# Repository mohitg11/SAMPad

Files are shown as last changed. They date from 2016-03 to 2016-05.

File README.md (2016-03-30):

# SAMPad

This is a custom numeric pad that is designed to be usable on the right side of the keyboard or on the left (With a mirrored layout if required).
There is a gap in the top row and the second row of 1.25U. The top row can be broken off by simply scoring the two brifges and snapping.
The bottom 5 rows can then be used in conjunction with a 60%/65% keyboard.

SAMPad stands for Sundstrand Adding Machine. David Sundstrand was the inventor of the 10-key adding machine, the layout of which is used till date on most numeric pads. This is a humble dedication to the great man.

#Features
- Open Source Design
- Fully Programmable Keys
- Numpad can be mirrored for use on the left side of the main keyboard.
- Multiple layers
- Alps/Cherry (PCB/Plate) support
- PCB mount stabs supported
- Backlight, LED on bottom for windowed keycaps
- 6 Indicator LEDs, 4 on the top row and one on either Num Lock positions (Regular and mirrored)
- 4 SMD RGB LEDs on the bottom of the PCB for under/side glow
- SMD (SOD-123) diodes only
- Individual resistors for the LEDs not required as it uses a dedicated LED driver
- Using large (0805) capacitors and resistors so it is easier to hand-solder
- Possibility to add a buzzer
- Possibility to add a rotary dial on the top-right most key position for changing volume, LED brightness, etc.

#Layout options decided/implemented:
- Standard numpad with extra row on top with a 1.25U vertical offset that matches most TKL boards.
- Possibility for upto 5*4 + 4 keys layout
- Mirrored numpad layout for use on left side of main keyboard

In the below image you can see the different options available.
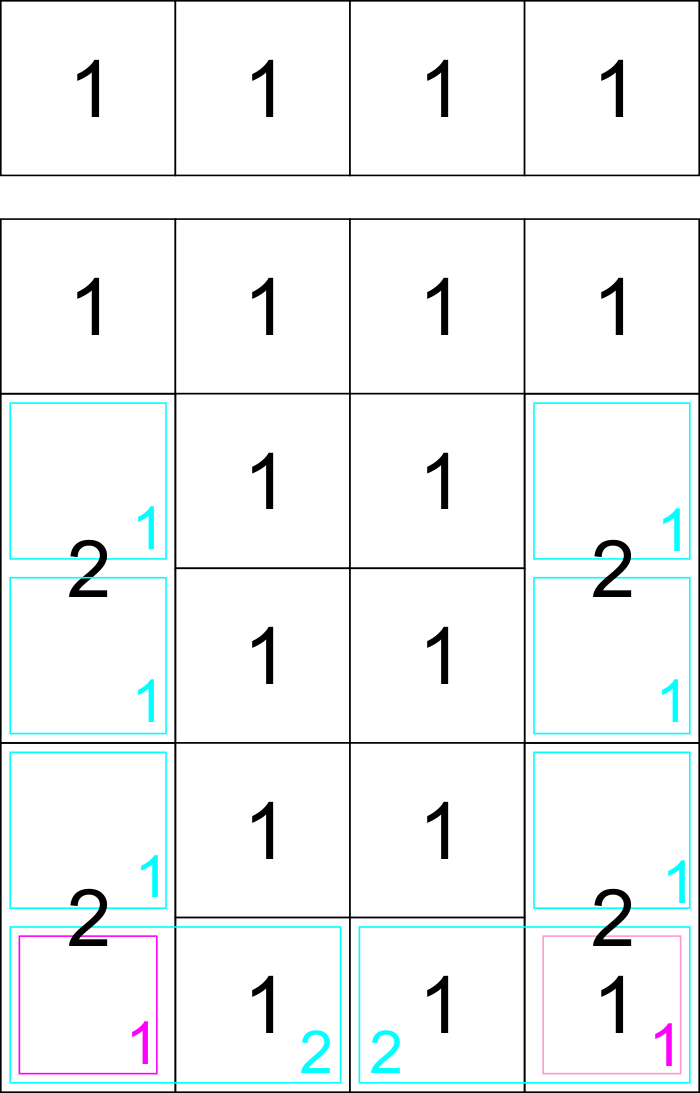
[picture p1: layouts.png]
Layout Options


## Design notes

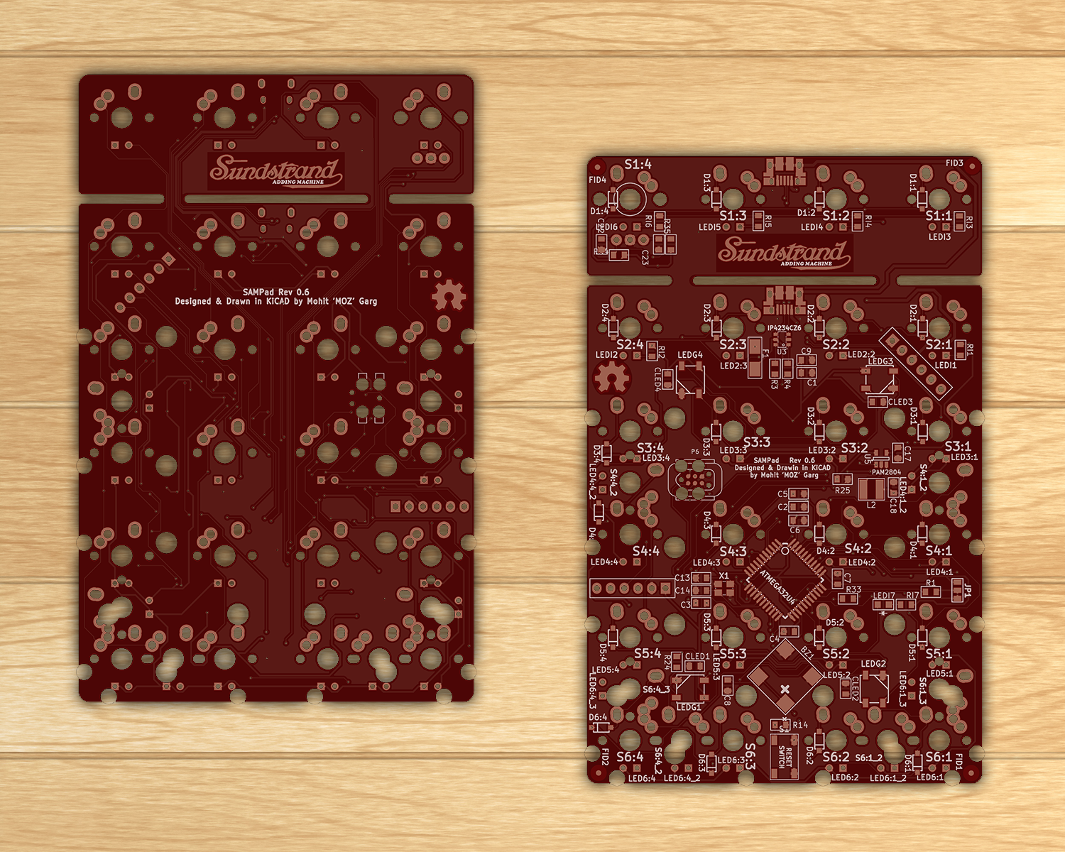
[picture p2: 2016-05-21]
PCB.png

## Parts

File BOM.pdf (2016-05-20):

# | Ref | Value | Qty | Description | Product | Vendor

1 | C1, C2 | 1uF | 2 | CAP CER 1UF 10V 10% X7R 0805 | CC0805KKX7R6BB105 | Yageo
2 | C13, C14 | 8pF | 2 | CAP CER 8PF 50V NP0 0805 | CC0805DRNPO9BN8R0 | Yageo
3 | C9, C17, C18 | 10uF | 3 | CAP CER 10UF 6.3V X5R 0805 | CC0805KKX5R5BB106 | Yageo
4 | CLED1 ‐ CLED4, C3‐C7 | 0.1 uF | 9 | CAP CER 0.1UF 16V X7R 0805 | CL21B104KOANNNC | Yageo
5 | D1:1 | 1N4148 | 24 | 1N4148 SOD123 DIODE | 1N4148W‐FDICT‐ND | Diodes Inc
6 | F1 | PTC FUSE | 1 | PTC RESTTBLE 1.0A 6V CHIP 1206 | 0ZCJ0100FF2E | Bel Fuse Inc
7 | L2 | 4.7uH | 1 | FIXED IND 4.7UH 1.9A 84 MOHM SMD | SRN4018‐4R7M | Bourns Inc
8 | LED1:1 ‐ LED6:4, :LEDI1 ‐ LEDI6 | LED | 24 | 2x3x4mm 1.8mm 3mm flangeless LED
9 | LEDG1 ‐ LEDG4 | WS2812B | 4 | LED RGB WS2812B W/DVR 4SMD 10PK | WS2812B | WorldSemi
10 | LEDI7 | LED | 1 | 0805 SMD LED
11 | P1 | USB_CONN | 1 | USB Micro B Female | 10103594‐0001LF | Amphenol
12 | R1 | 10k | 1 | RES SMD 10K OHM 1% 1/8W 0805 | RC0805FR‐0710KL | Yageo
13 | R24 | 330 | 1 | RES SMD 330 OHM 1% 1/8W 0805 | RC0805FR‐07330RL | Yageo
14 | R25 | RLED | 1 | Resistor to set LED current select 0.1/I | RL0805FR‐7W0R5L | Yageo
15 | R3, R4 | 22 | 2 | RES SMD 22 OHM 5% 1/8W 0805 | RC0805FR‐0722RL | Yageo
16 | R14 | 100k | 1 | RES SMD 100K OHM 1% 1/8W 0805 | RC0805FR‐07100KL | Yageo
17 | RI1 ‐ RI7 | 470 | 7 | 0805 Resistor for LED | RC0805FR‐07470KL | Yageo
18 | S1 | TAC_SWITCH | 1 | SWITCH TACTILE SPST‐NO 0.02A 15V | PTS525SM15SMTR2 LFS | C&K Components
19 | S1:1 | SW | 24 | MX Alps or compatible switch
20 | U1 | ATMEGA32U4 | 1 | IC MCU 8BIT 32KB FLASH 44TQFP | ATMEGA32U4‐AU | Atmel
21 | U3 | IP4234CZ6 | 1 | TVS DIODE 5.5VWM 6TSOP | IP4234CZ6 | NXP
22 | U5 | PAM2804 | 1 | LED Driver IC 1 Output DC DC Buck 1A | PAM2804AAB010 | Diodes Inc
23 | X1 | 16Mhz | 1 | Crystal 16.0000MHz 15ppm 8pF 50 Ohm | NX3225SA‐16.000MHZ‐STD‐CSR‐1 | NDK
# | Buzzer (Optional)

1 | BZ1 | BUZZER | 1 | BUZZER MAGNETIC 3.6V 8.5MM SMD | SMT‐0931‐S‐R | PUI Audio Inc
2 | C8 | 0.1 uF | 1 | CAP CER 0.1UF 16V X7R 0805 | CL21B104KOANNNC | Yageo
3 | R33 | 100 | 1 | RES SMD 100 OHM 1% 1/8W 0805 | RC0805FR‐07100RL | Yageo
# | Encoder (Optional)

1 | C22, C23 | 1uF | 2 | CAP CER 1UF 10V 10% X7R 0805 | CC0805KKX7R6BB105 | Yageo
2 | R34, R35 | 10k | 2 | RES SMD 10K OHM 1% 1/8W 0805 | RC0805FR‐0710KL | Yageo
3 | S2 | ENCODER | 1 | ENCODER ROTARY | PEC12R‐4017F‐N0024 | Bourns Inc

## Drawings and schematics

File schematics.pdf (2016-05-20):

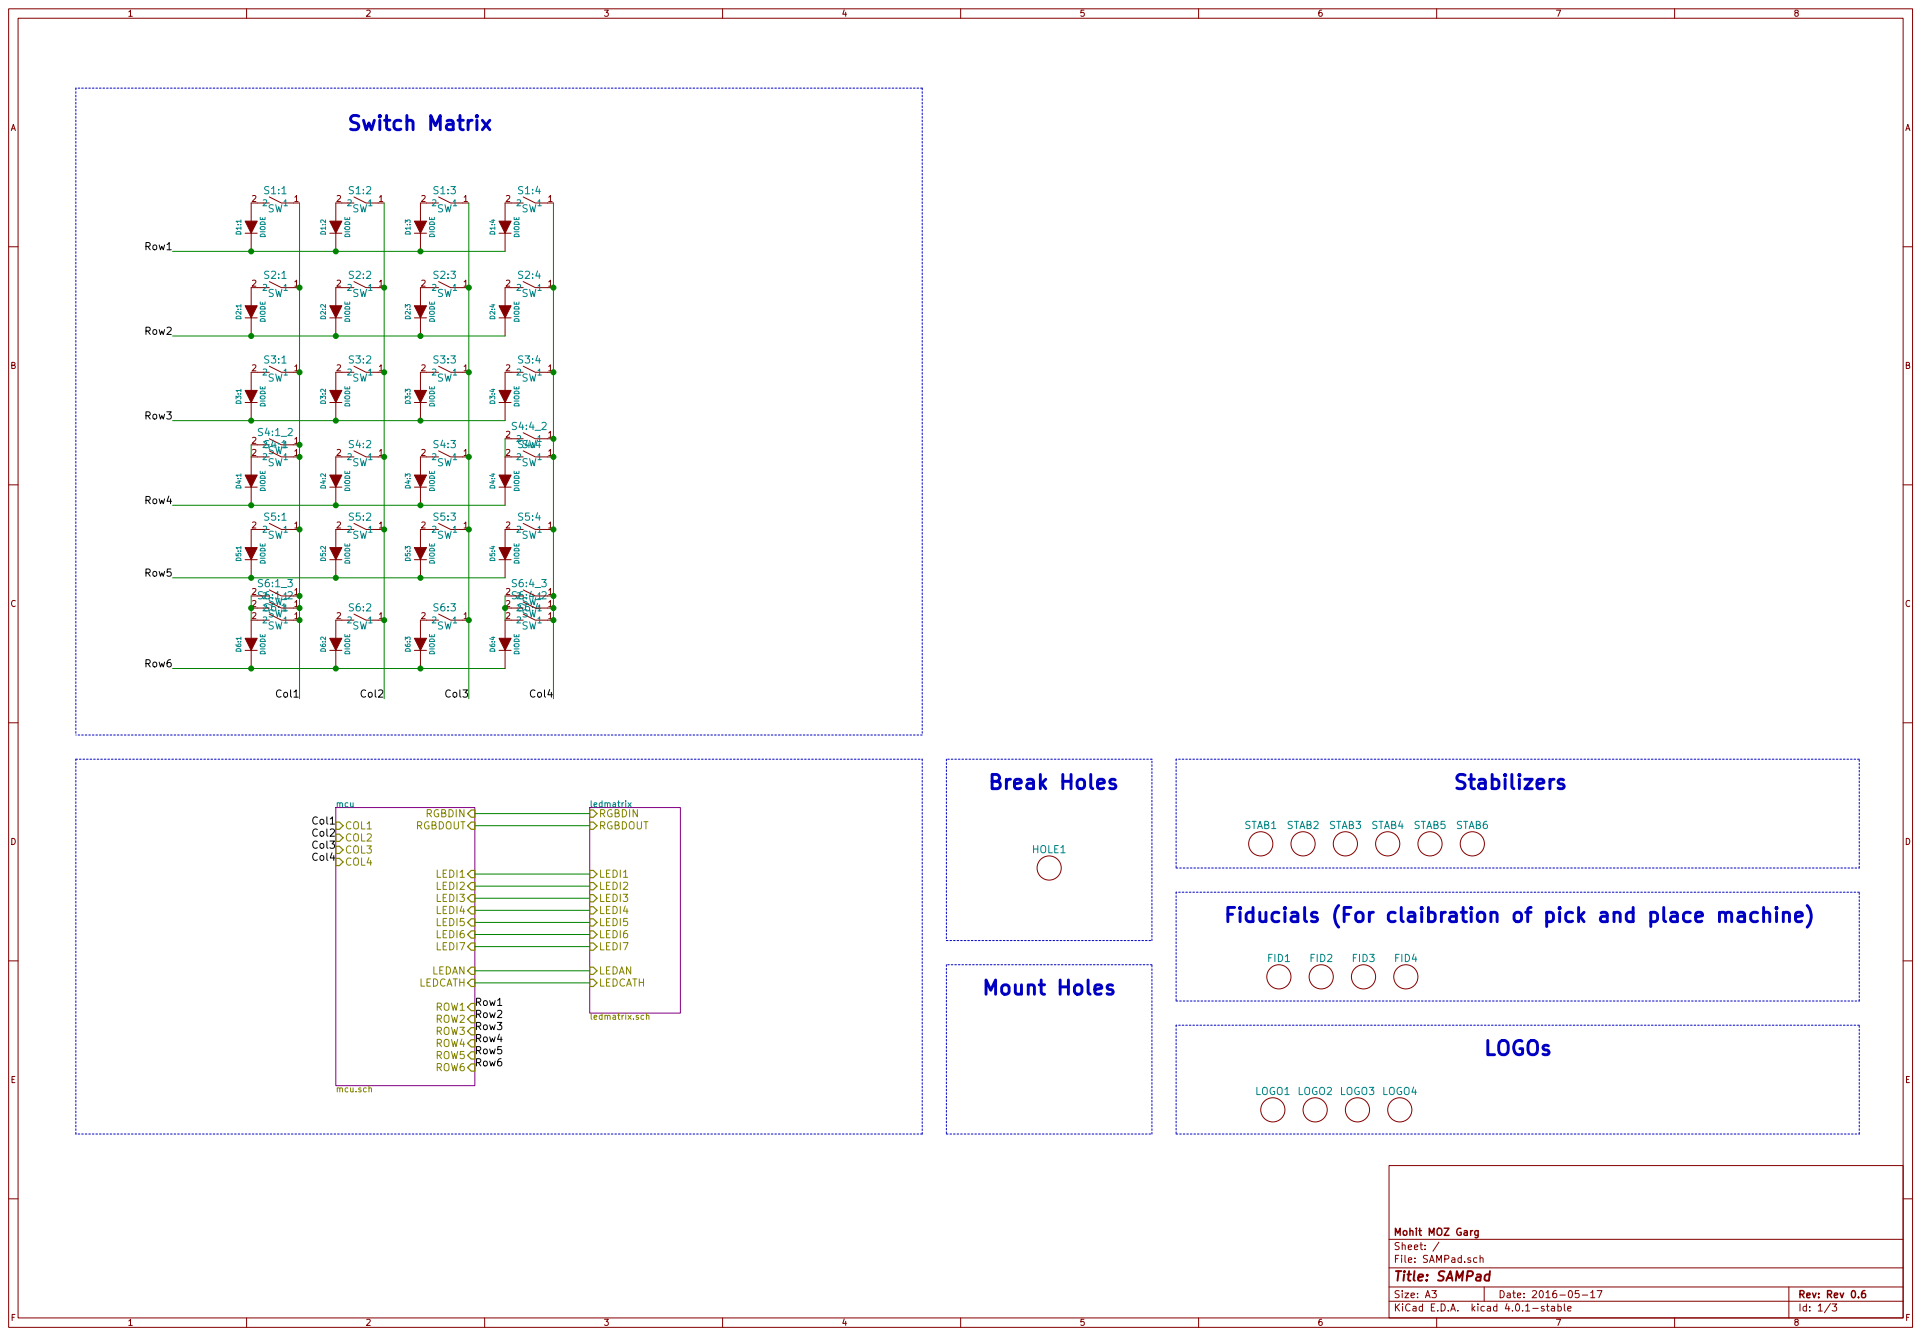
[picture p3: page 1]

Fiducials (For claibration of pick and place machine)

File: SAMPad.sch Sheet: / Mohit MOZ Garg

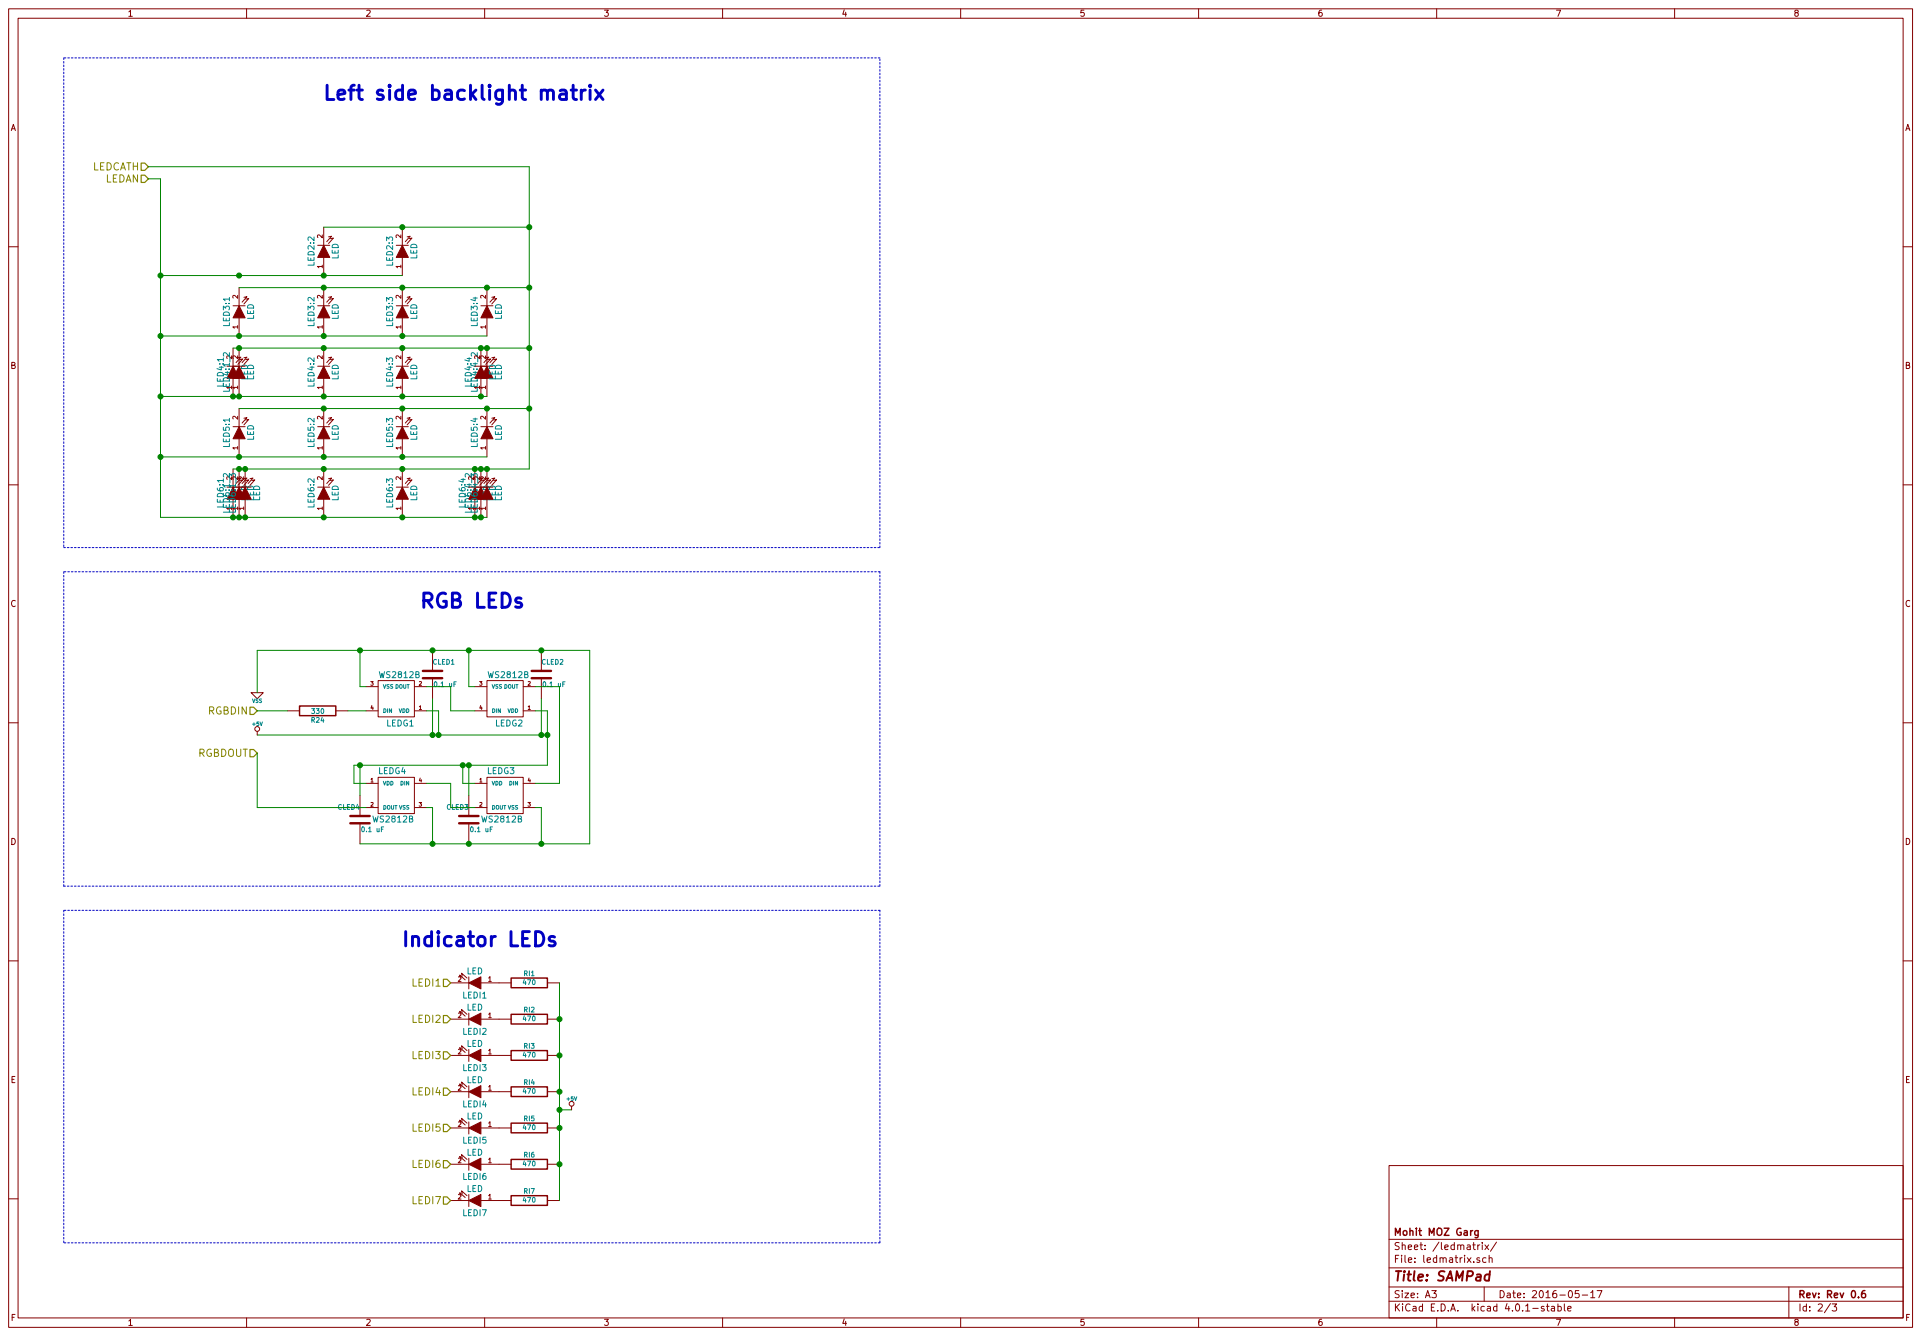
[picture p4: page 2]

Left side backlight matrix

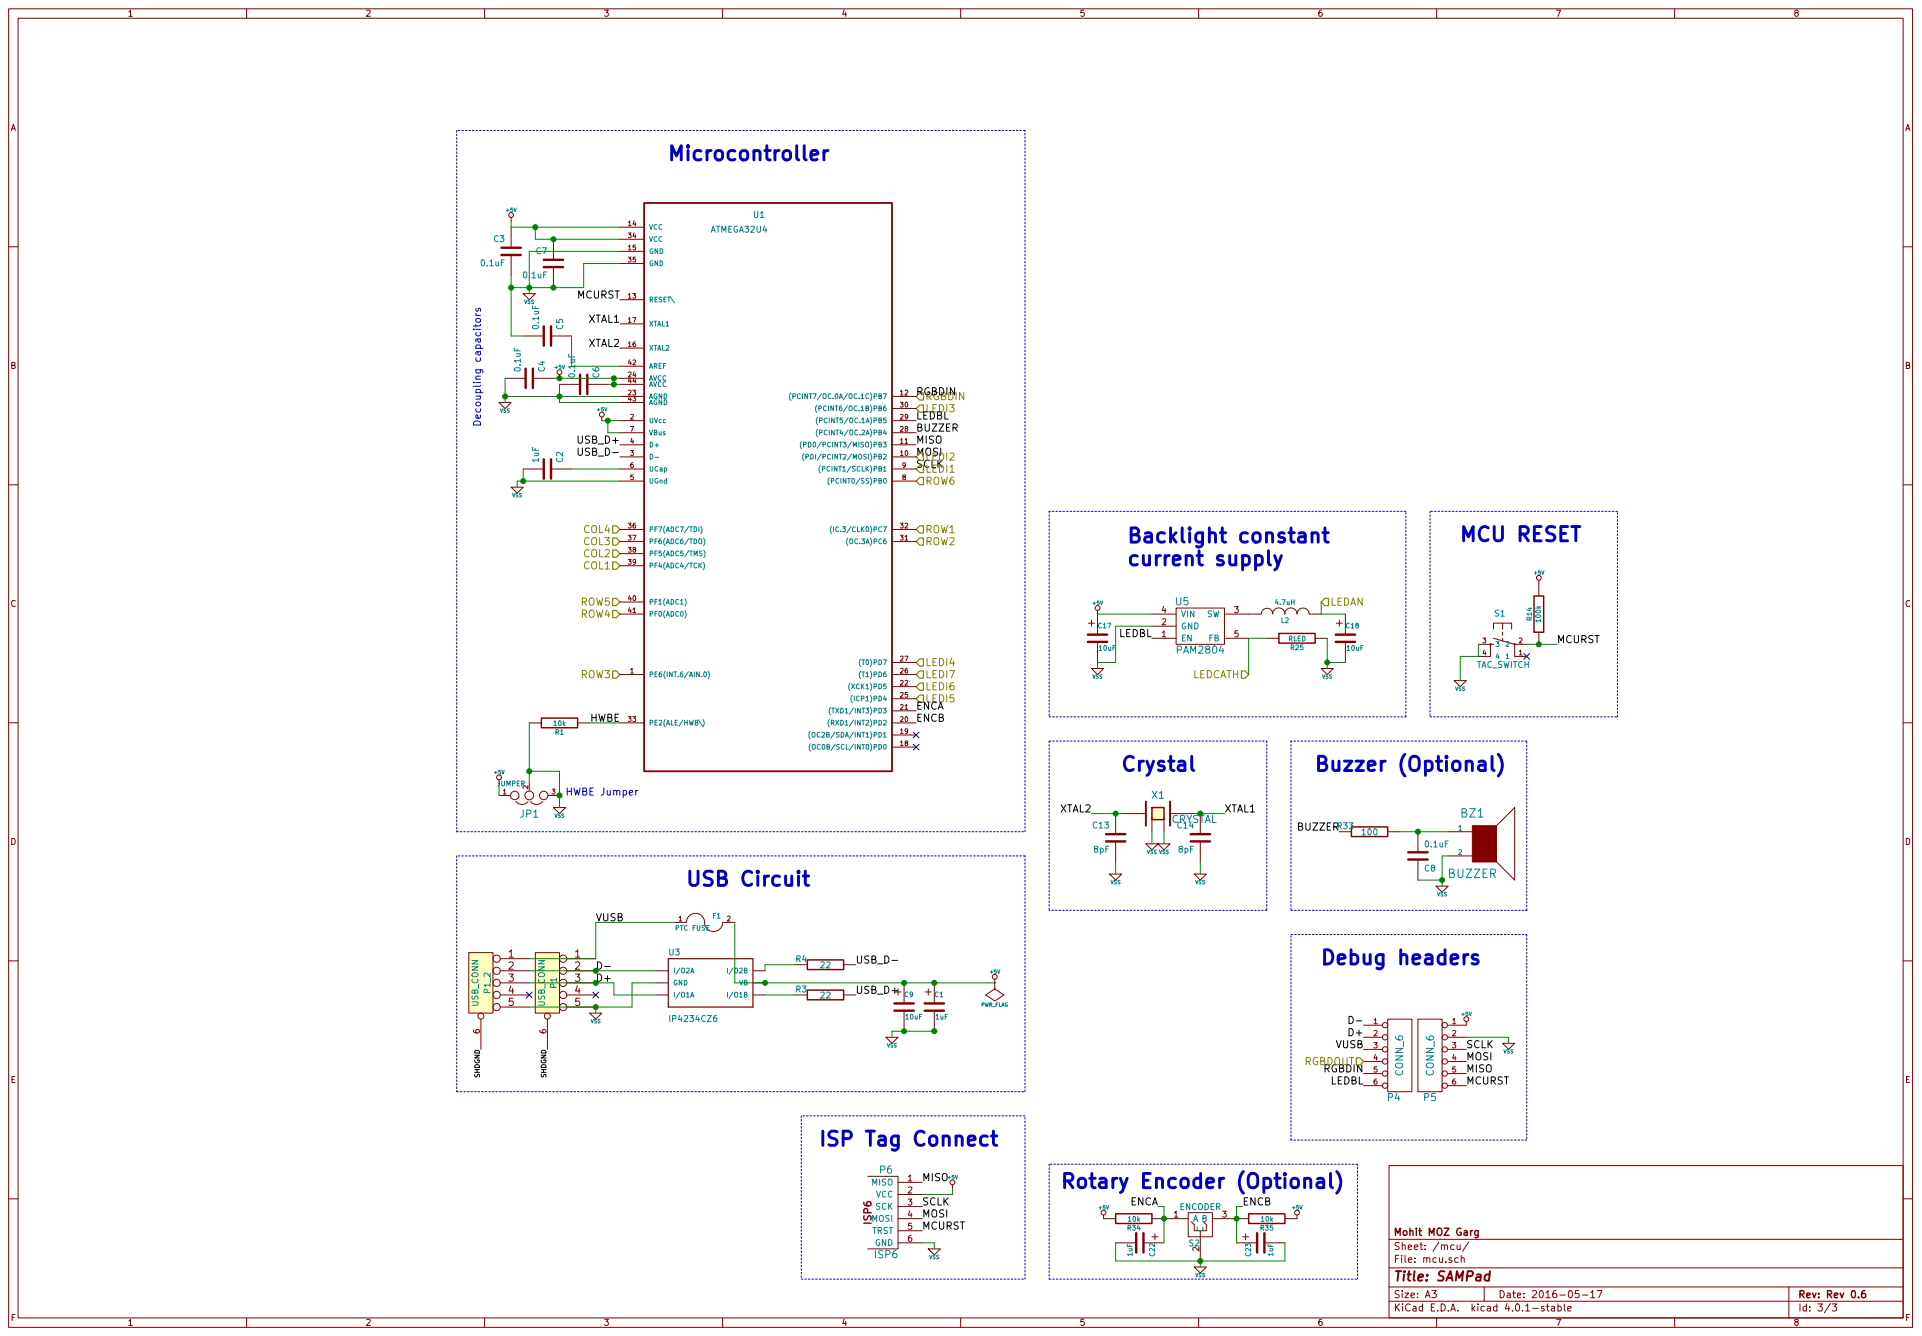
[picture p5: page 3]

VSS BUZZER Buzzer (Optional)

File: mcu.sch Sheet: /mcu/ Mohit MOZ Garg

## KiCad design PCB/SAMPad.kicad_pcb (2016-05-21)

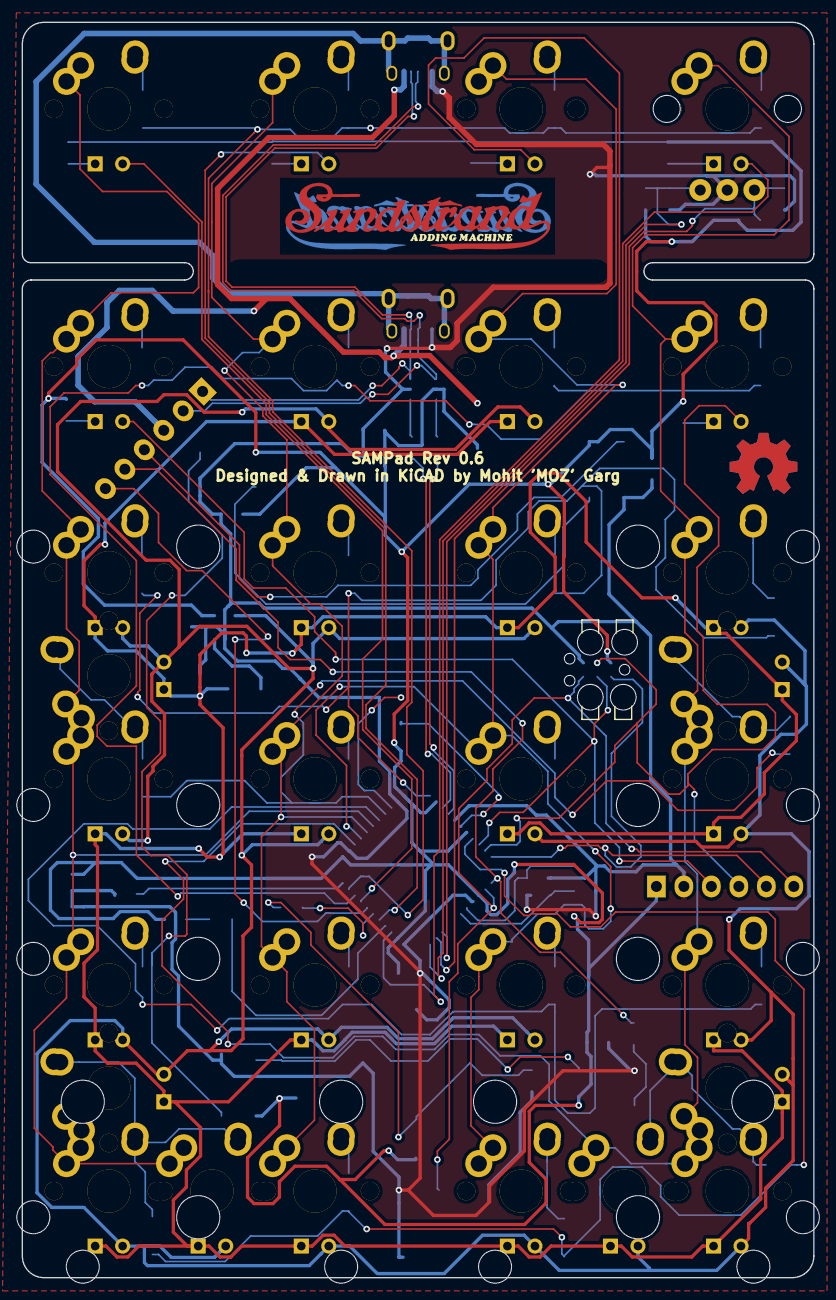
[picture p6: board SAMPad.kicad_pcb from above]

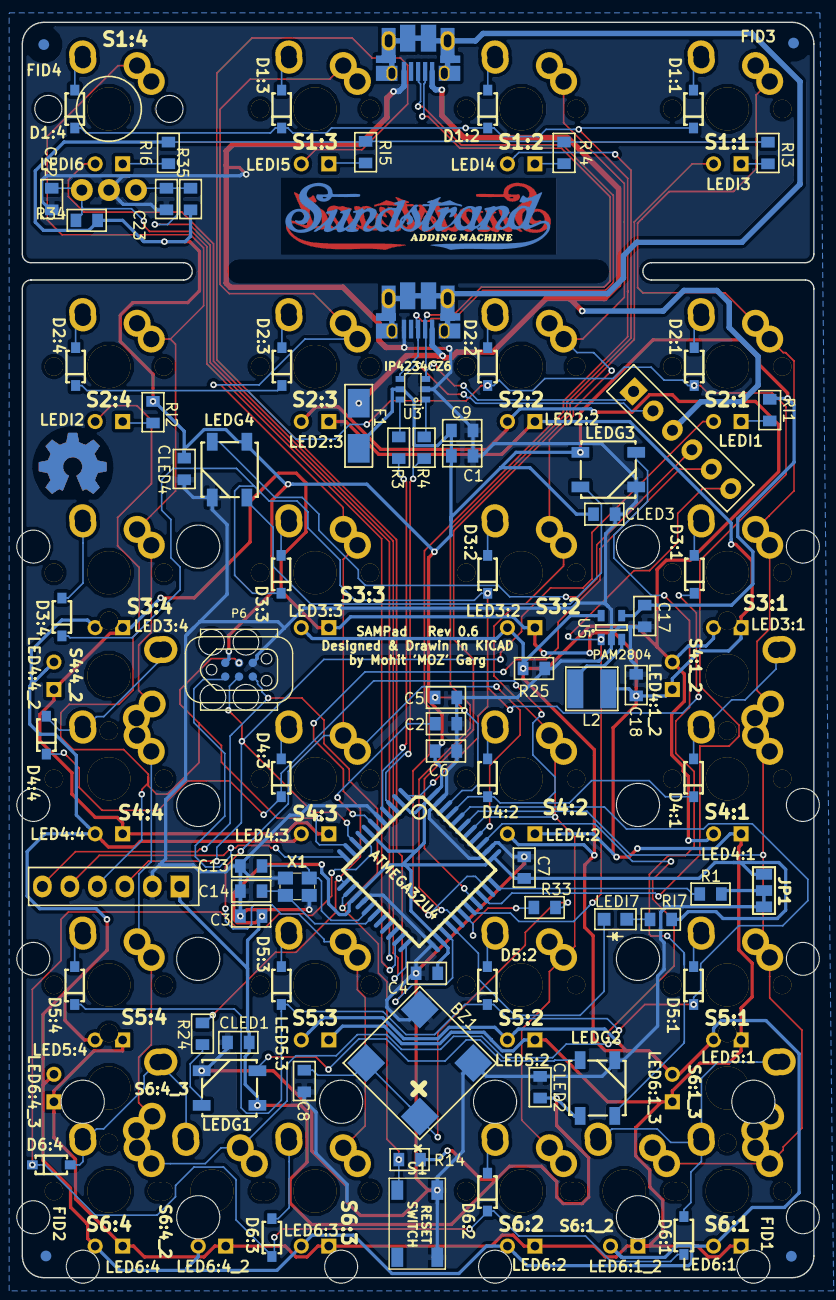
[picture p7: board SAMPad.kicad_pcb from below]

Board: 2 copper layers, 73.2 x 116.0 mm, 154 parts (85 on the bottom side), 79 nets.

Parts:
BZ1: BUZZER; BUZZER_SMT
C1, C2, C22, C23: 1uF; SMD_0805
C3, C4, C5, C6, C7, C8: 0.1uF; SMD_0805
C9, C17, C18: 10uF; SMD_0805
C13, C14: 8pF; SMD_0805
CLED1, CLED2, CLED3, CLED4: 0.1 uF; SMD_0805
D1:1, D1:2, D1:3, D1:4, D2:1, D2:2, D2:3, D2:4, D3:1, D3:2, D3:3, D3:4, D4:1, D4:2, D4:3, D4:4, D5:1, D5:2, D5:3, D5:4, D6:1, D6:2, D6:3, D6:4: DIODE; SOD123-DIODE
F1: PTC FUSE; Fuse_SMD1206
FID1, FID2, FID3, FID4: MISC; FID
HOLE1: MISC; FID
JP1: JUMPER; JUMPER_SMD_3
L2: 4.7uH; Inductor_Bourn_4mmx4mm
LED2:2, LED2:3, LED3:1, LED3:2, LED3:3, LED3:4, LED4:1, LED4:1_2, LED4:2, LED4:3, LED4:4, LED4:4_2, LED5:1, LED5:2, LED5:3, LED5:4, LED6:1, LED6:1_2, LED6:1_3, LED6:2, LED6:3, LED6:4, LED6:4_2, LED6:4_3: LED; INSW_LEDS_REG
LEDG1, LEDG2, LEDG3, LEDG4: WS2812B
LEDI1, LEDI2, LEDI3, LEDI4, LEDI5, LEDI6: LED; INSW_LEDS_REG
LEDI7: LED; LED_0805
LOGO1, LOGO2: MISC; SAMPad-Logo
LOGO3, LOGO4: MISC; OSHW
P1, P1_2: USB_CONN; USB_Micro-B
P4, P5: CONN_6; Pin_Header_1x06
P6: ISP6; TC2030_BIG
R1, R34, R35: 10k; SMD_0805
R3, R4: 22; SMD_0805
R14: 100k; SMD_0805
R24: 330; SMD_0805
R25: RLED; SMD_0805
R33: 100; SMD_0805
RI1, RI2, RI3, RI4, RI5, RI6, RI7: 470; SMD_0805
S1: TAC_SWITCH; TACT_5.2x5.2
S1:1, S1:2, S1:3, S1:4, S2:1, S2:2, S2:3, S2:4, S3:1, S3:2, S3:3, S3:4, S4:1, S4:1_2, S4:2, S4:3, S4:4, S4:4_2, S5:1, S5:2, S5:3, S5:4, S6:1, S6:1_2, S6:1_3, S6:2, S6:3, S6:4, S6:4_2, S6:4_3: SW; MXALPS2
S2: ENCODER; ENCODER_12MM
STAB1, STAB2, STAB3, STAB4, STAB5, STAB6: MISC; MX_200
U1: ATMEGA32U4; TQFP44
U3: IP4234CZ6; SOT457
U5: PAM2804; SOT-23-5
X1: CRYSTAL; NX3225SA

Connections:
+5V: C1.1, C3.1, C4.1, C6.1, C7.1, C9.1, C17.1, CLED1.2, CLED2.2, CLED3.1, CLED4.1, F1.2, JP1.1, LEDG1.1, LEDG2.1, LEDG3.1, LEDG4.1, P5.1, P6.2, R14.2, R34.2, R35.1, RI1.2, RI2.2, RI3.2, RI4.2, RI5.2, RI6.2, RI7.2, U1.2, U1.7, U1.14, U1.24, U1.34, U1.44, U3.5, U5.4
/ledmatrix/LEDAN: C18.1, L2.2, LED2:2.1, LED2:3.1, LED3:1.1, LED3:2.1, LED3:3.1, LED3:4.1, LED4:1.1, LED4:1_2.1, LED4:2.1, LED4:3.1, LED4:4.1, LED4:4_2.1, LED5:1.1, LED5:2.1, LED5:3.1, LED5:4.1, LED6:1.1, LED6:1_2.1, LED6:1_3.1, LED6:2.1, LED6:3.1, LED6:4.1, LED6:4_2.1, LED6:4_3.1
/ledmatrix/LEDCATH: LED2:2.2, LED2:3.2, LED3:1.2, LED3:2.2, LED3:3.2, LED3:4.2, LED4:1.2, LED4:1_2.2, LED4:2.2, LED4:3.2, LED4:4.2, LED4:4_2.2, LED5:1.2, LED5:2.2, LED5:3.2, LED5:4.2, LED6:1.2, LED6:1_2.2, LED6:1_3.2, LED6:2.2, LED6:3.2, LED6:4.2, LED6:4_2.2, LED6:4_3.2, R25.2, U5.5
/ledmatrix/LEDI1: LEDI1.2, P5.3, P6.3, U1.9
/ledmatrix/LEDI2: LEDI2.2, P5.4, P6.4, U1.10
/ledmatrix/LEDI3: LEDI3.2, U1.30
/ledmatrix/LEDI4: LEDI4.2, U1.27
/ledmatrix/LEDI5: LEDI5.2, U1.25
/ledmatrix/LEDI6: LEDI6.2, U1.22
/ledmatrix/LEDI7: LEDI7.2, U1.26
/ledmatrix/RGBDIN: P4.5, R24.2, U1.12
/ledmatrix/RGBDOUT: LEDG4.2, P4.4
/mcu/BUZZER: R33.1, U1.28
/mcu/COL1: S1:1.1, S2:1.1, S3:1.1, S4:1.1, S4:1_2.1, S5:1.1, S6:1.1, S6:1_2.1, S6:1_3.1, U1.39
/mcu/COL2: S1:2.1, S2:2.1, S3:2.1, S4:2.1, S5:2.1, S6:2.1, U1.38
/mcu/COL3: S1:3.1, S2:3.1, S3:3.1, S4:3.1, S5:3.1, S6:3.1, U1.37
/mcu/COL4: S1:4.1, S2:4.1, S3:4.1, S4:4.1, S4:4_2.1, S5:4.1, S6:4.1, S6:4_2.1, S6:4_3.1, U1.36
/mcu/D+: P1.3, P1_2.3, P4.2, U3.4
/mcu/D-: P1.2, P1_2.2, P4.1, U3.3
/mcu/ENCA: C22.1, R34.1, S2.1, U1.21
/mcu/ENCB: C23.1, R35.2, S2.3, U1.20
/mcu/HWBE: R1.2, U1.33
/mcu/LEDBL: P4.6, U1.29, U5.1
/mcu/MCURST: P5.6, P6.5, R14.1, S1.2, U1.13
/mcu/MISO: P5.5, P6.1, U1.11
/mcu/ROW1: D1:1.2, D1:2.2, D1:3.2, D1:4.2, U1.32
/mcu/ROW2: D2:1.2, D2:2.2, D2:3.2, D2:4.2, U1.31
/mcu/ROW3: D3:1.2, D3:2.2, D3:3.2, D3:4.2, U1.1
/mcu/ROW4: D4:1.2, D4:2.2, D4:3.2, D4:4.2, U1.41
/mcu/ROW5: D5:1.2, D5:2.2, D5:3.2, D5:4.2, U1.40
/mcu/ROW6: D6:1.2, D6:2.2, D6:3.2, D6:4.2, U1.8
/mcu/SHDGND: P1.6, P1_2.6
/mcu/USB_D+: R3.2, U1.4
/mcu/USB_D-: R4.2, U1.3
/mcu/VUSB: F1.1, P1.1, P1_2.1, P4.3
/mcu/XTAL1: C14.1, U1.17, X1.3
/mcu/XTAL2: C13.1, U1.16, X1.1
unnamed: BZ1.1, C8.2, R33.2
unnamed: C2.1, U1.6
unnamed: C5.1, U1.42
unnamed: D1:1.1, S1:1.2
unnamed: D1:2.1, S1:2.2
unnamed: D1:3.1, S1:3.2
unnamed: D1:4.1, S1:4.2
unnamed: D2:1.1, S2:1.2
unnamed: D2:2.1, S2:2.2
unnamed: D2:3.1, S2:3.2
unnamed: D2:4.1, S2:4.2
unnamed: D3:1.1, S3:1.2
unnamed: D3:2.1, S3:2.2
unnamed: D3:3.1, S3:3.2
unnamed: D3:4.1, S3:4.2
unnamed: D4:1.1, S4:1.2, S4:1_2.2
unnamed: D4:2.1, S4:2.2
unnamed: D4:3.1, S4:3.2
unnamed: D4:4.1, S4:4.2, S4:4_2.2
unnamed: D5:1.1, S5:1.2
unnamed: D5:2.1, S5:2.2
unnamed: D5:3.1, S5:3.2
unnamed: D5:4.1, S5:4.2
unnamed: D6:1.1, S6:1.2, S6:1_2.2, S6:1_3.2
unnamed: D6:2.1, S6:2.2
unnamed: D6:3.1, S6:3.2
unnamed: D6:4.1, S6:4.2, S6:4_2.2, S6:4_3.2
unnamed: L2.1, U5.3
unnamed: LEDG1.2, LEDG2.4
unnamed: LEDG1.4, R24.1
unnamed: LEDG2.2, LEDG3.4
unnamed: LEDG3.2, LEDG4.4
unnamed: LEDI1.1, RI1.1
unnamed: LEDI2.1, RI2.1
unnamed: LEDI3.1, RI3.1
unnamed: LEDI4.1, RI4.1
unnamed: LEDI5.1, RI5.1
unnamed: LEDI6.1, RI6.1
unnamed: LEDI7.1, RI7.1
unnamed: R3.1, U3.6
unnamed: R4.1, U3.1
VSS: BZ1.2, C1.2, C2.2, C3.2, C4.2, C5.2, C6.2, C7.2, C8.1, C9.2, C13.2, C14.2, C17.2, C18.2, C22.2, C23.2, CLED1.1, CLED2.1, CLED3.2, CLED4.2, JP1.2, JP1.3, LEDG1.3, LEDG2.3, LEDG3.3, LEDG4.3, P1.5, P1_2.5, P5.2, P6.6, R1.1, R25.1, S1.3, S1.4, S2.2, U1.5, U1.15, U1.23, U1.35, U1.43, U3.2, U5.2, X1.2, X1.4

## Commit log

2016-03-31 Fix Possible UVCC error
    [SAMPad-B.Cu.gbr, SAMPad-B.Mask.gbr, SAMPad-B.SilkS.gbr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]
2016-04-15 Rev 0.2
    [BOM.xlsx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]
2016-04-15 Minor fixes to silkscreen
    [SAMPad-B.Cu.gbr, SAMPad-B.Mask.gbr, SAMPad-B.SilkS.gbr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]
2016-04-20 Rev 0.4 - Removed 3.3V regulator
    [SAMPad-B.Cu.gbl, SAMPad-B.Mask.gbs, SAMPad-B.SilkS.gbo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]
2016-04-20 BOM updated to Rev 0.4
    [BOM.xlsx]
2016-04-24 Add case
2016-04-25 Removed Shottky diode
    [BOM.xlsx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]
2016-04-26 Rev 0.5
    [SAMPad-B.Cu.gbl, SAMPad-B.Mask.gbs, SAMPad-B.SilkS.gbo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]
2016-04-28 Minor update to correct silkscreen on Rev 0.5
    [SAMPad-B.Cu.gbl, SAMPad-B.Mask.gbs, SAMPad-B.SilkS.gbo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]
2016-05-01 Minor revision update, corrected the UCAP connection on MCU
    [SAMPad-B.Cu.gbl, SAMPad-B.Mask.gbs, SAMPad-B.SilkS.gbo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]
2016-05-10 Update BOM
2016-05-20 Rev 0.6
    [BOM.xlsx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]
